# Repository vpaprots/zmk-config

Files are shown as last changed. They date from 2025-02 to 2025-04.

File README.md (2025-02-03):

# Hardware

- Processor module: EBYTE E73-2G4M08S1C module with nrf52840/aQFN chip
- Charger: BQ25895 I2C Controlled Single Cell 5-A Fast Charger with MaxCharge
- Connectors
   - USB1: keyboard/debug/DFU (not charging)
   - USB2: charging (up-to-12V with HVDCP)
   - ...

For details, limitations, design decisions, etc. see [Hardware README](easyeda/README.md)

# Bootloader 
brew install --cask gcc-arm-embedded
pip3 install intelhex
pip3 install --user adafruit-nrfutil
PATH=$PATH:$HOME/Library/Python/3.9/bin make BOARD=ferne all
```

```

Per-Key RGB

behaviors {
   pht: positional_hold_tap {
      compatible = "zmk,behavior-rgb-tap";
      #binding-cells = <2>;
      flavor = "hold-preferred";
      animation = &
      bindings = <&kp>, <&kp>;
      hold-trigger-key-positions = <1>;    // <---[[the W key]]
   };
};

- on/off (simplest)
- on/off dampened
-

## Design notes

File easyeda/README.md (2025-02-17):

```
 usb-pd - needs more parts (reference to app note and the two chips)
 power mux - might be more full-proof, but needs more programming for auto-detection
       - use one or the other
       - more heat management
 combine usb connectors - need to know more about usb spec, probably some sort of hub chip
       - too many moving parts and unknowns, expensive to experiment
       - dsel doesnt seem well documented 
          - i.e. use a usb mux, but will the nrf also do handshake ruining the original handshake?
          - need to clamp vbus for nrf to 5v, but, so tl431.. but only after power handshake
        - would had been better if nrf handled the entire D+/- BC1.2 handshake, but no library for non-standard connectors
        - This is all just too old, and new parts havent been well integrated yet
          - nrf should know about usb-c (need newer chips?)
          - TI should integrate usb-c into battery charger
          - BC1.2+non-standard-chargers are deprecated, probably going to get harder to get such chargers 5-10 years from now
          - but USB PD needs too many discrete, untested components
          - if you still wish USB-PD, excellent guide https://www.ti.com/lit/ta/sszt229/sszt229.pdf?ts=1730645092694
kscan at 1.8v - might still be a good idea, but.. need to select diodes with low voltage drop, unsure about current skree tails
          - level shifters and bucks/ldos for 3.3/5v for everything else? spi/i2c high-speed shifters?
ldo for screen & trackball - https://www.nklabs.com/post/2020/01/14/when-is-an-ldo-more-efficient-than-a-switching-power-converter
          - nrf forums say max 2ma when radio on (50ma total) on vdd, so be safe and provide separate source
          - need low drop out for when 3.3v->3v (cant use basic parts)
          - allows turning it off for extpower
multiple cells in series - could had used higher charge voltage at lower amps (less heat management)
          - need separate, per-cell protection (one extra chip)
          - need ldo/buck for 3.3/5v (more parts, different power requirements)
          - so many untested design modifications, might make battery life worse
- fuel cell - use built-in ADC in bq25 charger
          - needs to be programmed and curve trained.. 
          - 'just pay for someone's library'
          - fairly 'cheap' component, low power consumption, no extra pins

Note: this is written, at times, as instructions. Sometimes it is. And sometimes, I give up the intention of making this generic and just getting on with it working just for me; and the instructions are for the future, angrier version of me, when I forgot what I considered dangerous and forgot.

Note: treat batteries with respect you would give a table saw; its an extremely useful tool, but also powerful enough to take your fingers off. Whether this circuit is safe (and safe not just for the day but years) is for you to decide.

```

Freerouting.jar

https://hackaday.com/2022/10/10/lithium-ion-battery-circuitry-is-simple/

Final key positions (no screen, no trackball)

https://ryanis.cool/cosmos/beta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

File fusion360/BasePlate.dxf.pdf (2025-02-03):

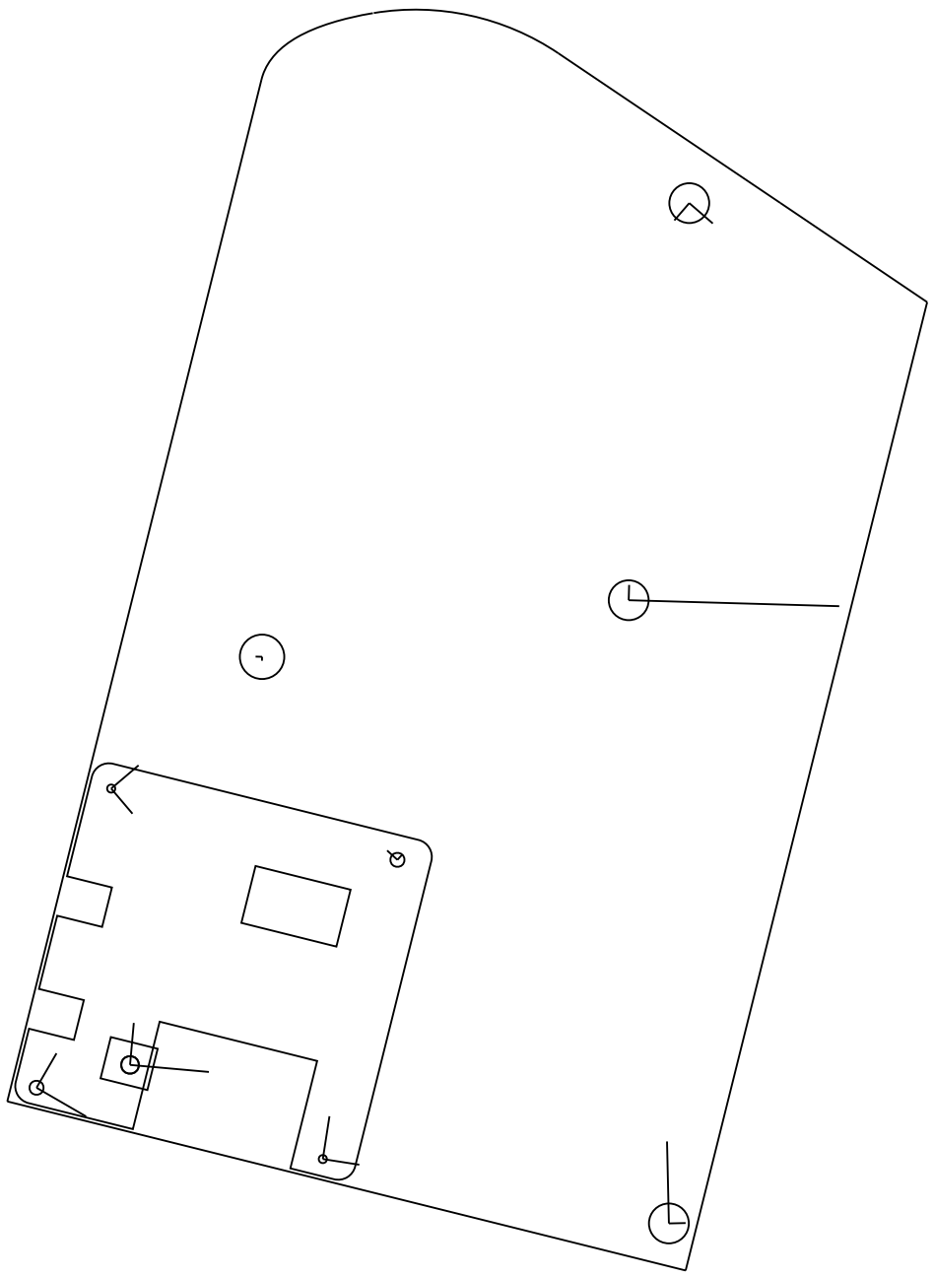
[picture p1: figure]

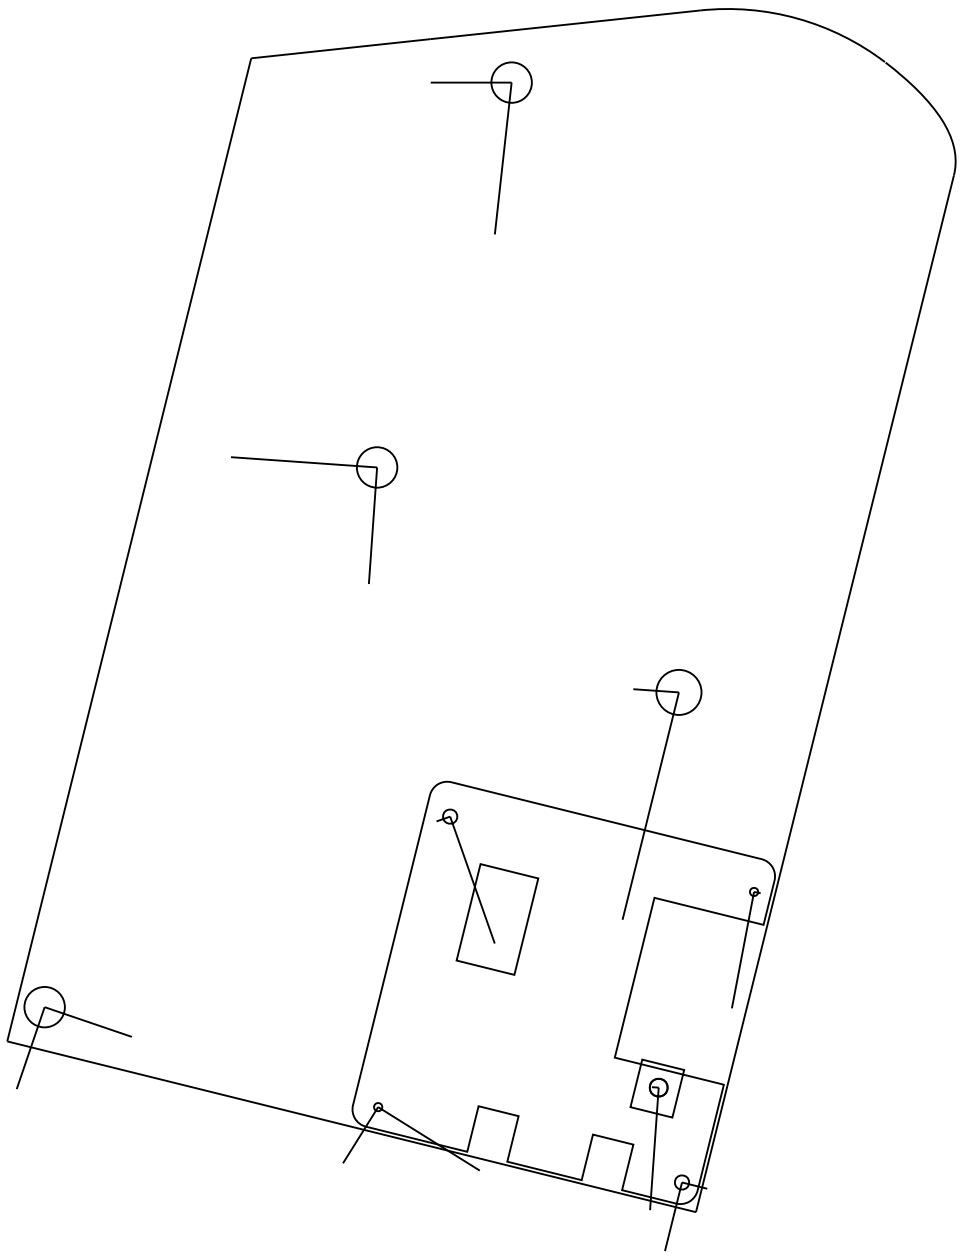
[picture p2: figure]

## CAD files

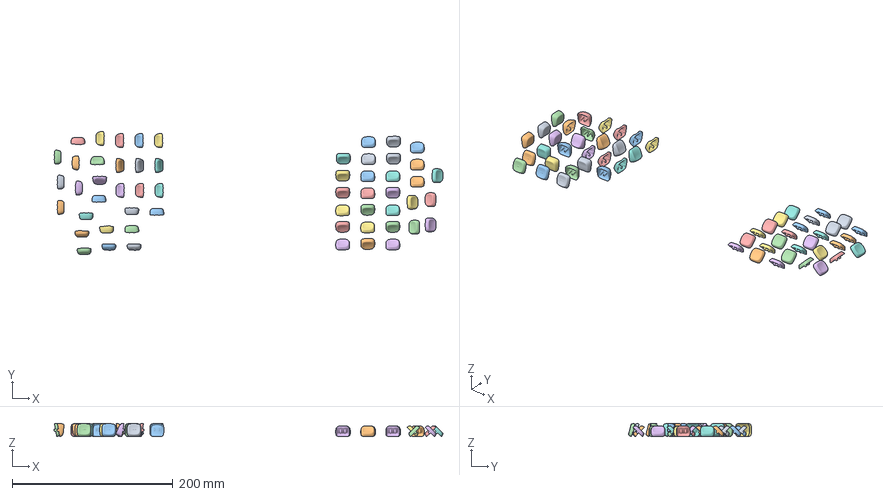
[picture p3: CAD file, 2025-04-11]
prusaslicer/KLP-0.25.3mf
484.7 x 153.3 x 16.4 mm
Body27.stl x 2
Body8.stl x 2

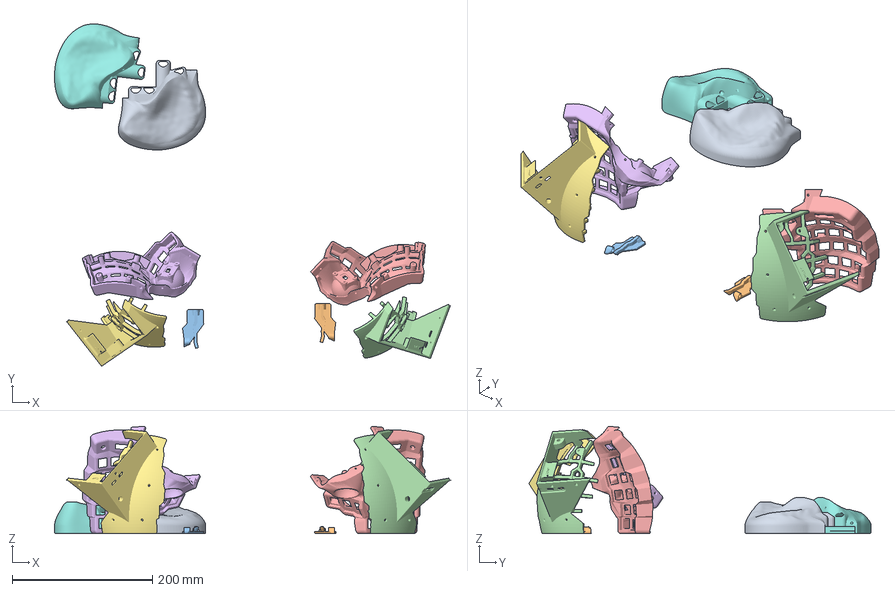
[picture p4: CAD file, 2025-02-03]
prusaslicer/case-sliced.3mf
565.1 x 488.1 x 153.4 mm
PalmrestR.stl
ThumbCoverR.stl
ThumbCover.stl
Box.stl
Keys.stl
KeysR.stl
BoxR.stl
Palmrest.stl

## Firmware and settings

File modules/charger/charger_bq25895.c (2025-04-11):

#define DT_DRV_COMPAT zmk_bq25895

#include <zephyr/device.h>
#include <zephyr/drivers/charger.h>
#include <zephyr/drivers/i2c.h>
#include <zephyr/drivers/gpio.h>
#include <zephyr/kernel.h>
#include <zephyr/logging/log.h>
#include <zephyr/sys/util.h>
#include <zephyr/drivers/sensor.h>

LOG_MODULE_REGISTER(bq25895, CONFIG_BQ25895_LOG_LEVEL);

#define BOOLF(name, register, bit, extra)
#define BOOL(name, register, bit, extra) int name;
#define INT(name, register, startbit, endbit, offset, scale, extra) int name;
#define INTA(name, register, startbit, endbit, offset, scale, extra) int name;
#include "bq25895_regs.h"
struct bq25895_config {
	struct i2c_dt_spec i2c;
    struct gpio_dt_spec irq_gpio;
	// all values shifted, as set in I2C registers
	BQ_CFG(0)
};

struct bq25895_data {
    BQ_ADC(0)
};

#undef BOOL
#undef INT
#undef BOOLF
#undef INTA

#ifdef CONFIG_BQ25895_LOG_LEVEL_DBG
#define INT(name, register, startbit, endbit, offset, scale, extra) \
dev_val = ((regs[register] & GENMASK(endbit, startbit))>> startbit) * scale + offset; \
cfg_val = (cfg->name >> startbit) * scale + offset; \
LOG_DBG("%s is set to %d, expect %d", #name, dev_val, cfg_val); 
#define BOOL(name, register, bit, extra) INT(name, register, bit, bit, 0, 1, extra)
#define INTA(name, register, startbit, endbit, offset, scale, extra) \
dev_val = ((regs[register-0xe] & GENMASK(endbit, startbit))>> startbit) * scale + offset; \
LOG_DBG("%s is measured at %d", #name, dev_val);
#include "bq25895_regs.h"
static void dump_settings(const struct device *dev, uint8_t* regs) {
	const struct bq25895_config *cfg = dev->config;
	int cfg_val, dev_val;
	BQ_CFG(0)
}

static void dump_adc(const struct device *dev, uint8_t* regs) {
	int dev_val;
	BQ_ADC(0)
}
#undef BOOL
#undef INT
#undef BOOLF
#undef INTA
#endif //CONFIG_BQ25895_LOG_LEVEL_DBG

#define BOOLF(name, register, bit, extra) \
static int set_##name(const struct bq25895_config *cfg) { \
	return i2c_reg_update_byte_dt(&cfg->i2c, register, GENMASK(bit,bit), GENMASK(bit,bit)); \
}
#define INT(name, register, startbit, endbit, offset, scale, extra) \
	if (cfg->name != (GENMASK(endbit, startbit) & regs[register])) { \
		LOG_DBG("Updating %s to %d", #name, cfg->name); \
		ret = i2c_reg_update_byte_dt(&cfg->i2c, register, GENMASK(endbit, startbit), cfg->name); \
		if (ret < 0) { return ret; } \
	}
#define BOOL(name, register, bit, extra) INT(name, register, bit, bit, 0, 1, extra)
#define INTA(name, register, startbit, endbit, offset, scale, extra) \
	drv_data->name = ((GENMASK(endbit, startbit) & regs[register - 0xE]) >> startbit) * scale + offset;

#include "bq25895_regs.h"

BQ_ACTION(0)

static int bq25895_init(const struct device *dev) {
	const struct bq25895_config *cfg = dev->config;
	uint8_t val;
	int ret;

	// check readiness of irq gpio pin
    if (!device_is_ready(cfg->irq_gpio.port)) {
        LOG_ERR("IRQ GPIO device not ready!");
        return -ENODEV;
    }

	if (!device_is_ready(cfg->i2c.bus)) {
        LOG_WRN("I2C BUS not ready!");
        return -ENODEV;
    }

	// init the irq pin
    ret = gpio_pin_configure_dt(&cfg->irq_gpio, GPIO_INPUT);
    if (ret) {
        LOG_ERR("Cannot configure IRQ GPIO");
        return ret;
    }

    // setup and add the irq callback associated
    // gpio_init_callback(&data->irq_gpio_cb, pmw3610_gpio_callback, BIT(cfg->irq_gpio.pin));

    // err = gpio_add_callback(config->irq_gpio.port, &data->irq_gpio_cb);
    // if (err) {
    //     LOG_ERR("Cannot add IRQ GPIO callback");
    // }

	uint8_t regs[0x15];
	ret = i2c_burst_read_dt(&cfg->i2c, 0, (uint8_t *)&regs, sizeof(regs)/sizeof(uint8_t));
	if (ret < 0) {
		LOG_ERR("Error reading registers: %02x", ret);
		return ret;
	}

	#ifdef CONFIG_BQ25895_LOG_LEVEL_DBG
	for (int i=0; i<sizeof(regs)/sizeof(uint8_t); i++) {
		//LOG_DBG("Reg BQ25895 %d set to %d", i, regs[i]);
	}
	dump_settings(dev, regs);
	#endif //CONFIG_BQ25895_LOG_LEVEL_DBG

	val = (regs[0x14]&GENMASK(5,3))>>3;
	if (val != 0b000111) {
		LOG_ERR("Invalid device id: %02x", val);
		return -EINVAL;
	}

	// Put bq25895 into host mode
	ret = set_wd_rst(cfg);
	if (ret < 0) {
		return ret;
	}

	// Correct any mismatched config values
	BQ_CFG(0);

	#ifdef CONFIG_BQ25895_LOG_LEVEL_DBG
	ret = i2c_burst_read_dt(&cfg->i2c, 0, (uint8_t *)&regs, sizeof(regs)/sizeof(uint8_t));
	if (ret < 0) {
		return ret;
	}
	dump_settings(dev, regs);
	#endif //CONFIG_BQ25895_LOG_LEVEL_DBG
	return 0;
}

static int bq25895_sample_fetch(const struct device *dev, enum sensor_channel chan) {
	bool valid_chan = chan == SENSOR_CHAN_GAUGE_STATE_OF_CHARGE || chan == SENSOR_CHAN_GAUGE_VOLTAGE || chan == SENSOR_CHAN_ALL;
	if (!valid_chan) {
        LOG_DBG("unsupported channel %d", chan);
        return -ENOTSUP;
    }

	const struct bq25895_config *cfg = dev->config;
    int ret;
	ret = set_conv_start(cfg);
	k_sleep(K_SECONDS(1));
	
	uint8_t regs[0x15]; ret = i2c_burst_read_dt(&cfg->i2c, 0, (uint8_t *)&regs, sizeof(regs)/sizeof(uint8_t));
	//uint8_t regs[5];
	//ret = i2c_burst_read_dt(&cfg->i2c, 0x0E, (uint8_t *)&regs, sizeof(regs)/sizeof(uint8_t));
	if (ret < 0) {
		LOG_ERR("Error reading registers: %02x", ret);
		return ret;
	}

	#ifdef CONFIG_BQ25895_LOG_LEVEL_DBG
	for (int i=0; i<sizeof(regs)/sizeof(uint8_t); i++) {
		//LOG_DBG("ADC Reg %d set to %d", i+0xE, regs[i]);
		LOG_DBG("Reg %d set to %d", i, regs[i]);
	}
	dump_settings(dev, regs);
	dump_adc(dev, regs);
	#endif //CONFIG_BQ25895_LOG_LEVEL_DBG

	// set drv_data
	struct bq25895_data *const drv_data = dev->data;
	BQ_ADC(0);
	return 0;
}
#undef BOOL
#undef INT
#undef BOOLF
#undef INTA

static int bq25895_channel_get(const struct device *dev, enum sensor_channel chan,
                                struct sensor_value *val) {
    int err = 0;
	
	struct bq25895_data *const drv_data = dev->data;
    int bat_voltage = drv_data->batv;
	LOG_DBG("ADC bat_voltage is measured at %d mV", bat_voltage);

    switch (chan) {
    case SENSOR_CHAN_GAUGE_VOLTAGE:
		LOG_DBG("ADC+ bat_voltage is measured at %d mV", bat_voltage);
        // 1250 / 16 = 78.125
        uint64_t tmp = bat_voltage * 1250 / 16;
        val->val1 = tmp / 1000000;
        val->val2 = tmp % 1000000;
        break;

    case SENSOR_CHAN_GAUGE_STATE_OF_CHARGE:
		LOG_DBG("ADC- bat_voltage is measured at %d mV", bat_voltage);
        val->val1 = (bat_voltage >> 8);
        val->val2 = (bat_voltage & 0xFF) * 1000000 / 256;
        break;

    default:
        err = -ENOTSUP;
        break;
    }

    return err;
}

static const struct sensor_driver_api bq25895_sensor_api = {
	.sample_fetch = bq25895_sample_fetch,
	.channel_get = bq25895_channel_get
};
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

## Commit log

2025-02-03 checkpoint. keyboard assembled, working on trackball and display
    [case-sliced.3mf, flash.cfg, nrf.cfg]
2025-02-07 trackball and power-domain
2025-04-11 checkpoint: BQ25895 driver sorta works, STRDY keymap
    [KLP-0.25.3mf]
